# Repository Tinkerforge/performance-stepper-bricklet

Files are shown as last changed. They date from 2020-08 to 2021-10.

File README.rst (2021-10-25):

Performance Stepper Bricklet
============================

**This Bricklet is currently in development.**

This repository contains the firmware source code and the hardware design
files. The documentation generator configs can be found at
https://github.com/Tinkerforge/generators

Repository Content
------------------

software/:
 * examples/: Examples for all supported languages
 * build/: Compiled files
 * src/: Source code of firmware
 * Makefile: Makefile to build project

hardware/:
 * Contains KiCad project files and additionally schematics as PDF

datasheets/:
 * Contains datasheets for sensors and complex ICs that are used

Hardware
--------

The hardware is designed with the open source EDA Suite KiCad
(http://www.kicad.org). Before you are able to open the files,
you have to install the Tinkerforge kicad-libraries
(https://github.com/Tinkerforge/kicad-libraries). You can either clone
them directly in hardware/ or clone them in a separate folder and
symlink them into hardware/
(ln -s kicad_path/kicad-libraries project_path/hardware). After that you
can open the .pro file in hardware/ with KiCad and from there view and
modify the schematics and the PCB layout.

Software
--------

If you want to do your own Brick/Bricklet firmware development we highly
recommend that you use our build environment setup script and read the
tutorial (https://www.tinkerforge.com/en/doc/Tutorials/Tutorial_Build_Environment/Tutorial.html).

To compile the C code we recommend you to install the newest GNU Arm Embedded
Toolchain (https://launchpad.net/gcc-arm-embedded/+download).
You also need to install bricklib2 (https://github.com/Tinkerforge/bricklib2).

You can either clone it directly in software/src/ or clone it in a
separate folder and symlink it into software/src/
(ln -s bricklib_path/bricklib2 project_path/software/src/). Finally make sure to
have CMake installed (http://www.cmake.org/cmake/resources/software.html).

After that you can build the firmware by invoking make in software/.
The firmware (.zbin) can then be found in software/build/ and uploaded
with brickv (click button "Flashing" on start screen).

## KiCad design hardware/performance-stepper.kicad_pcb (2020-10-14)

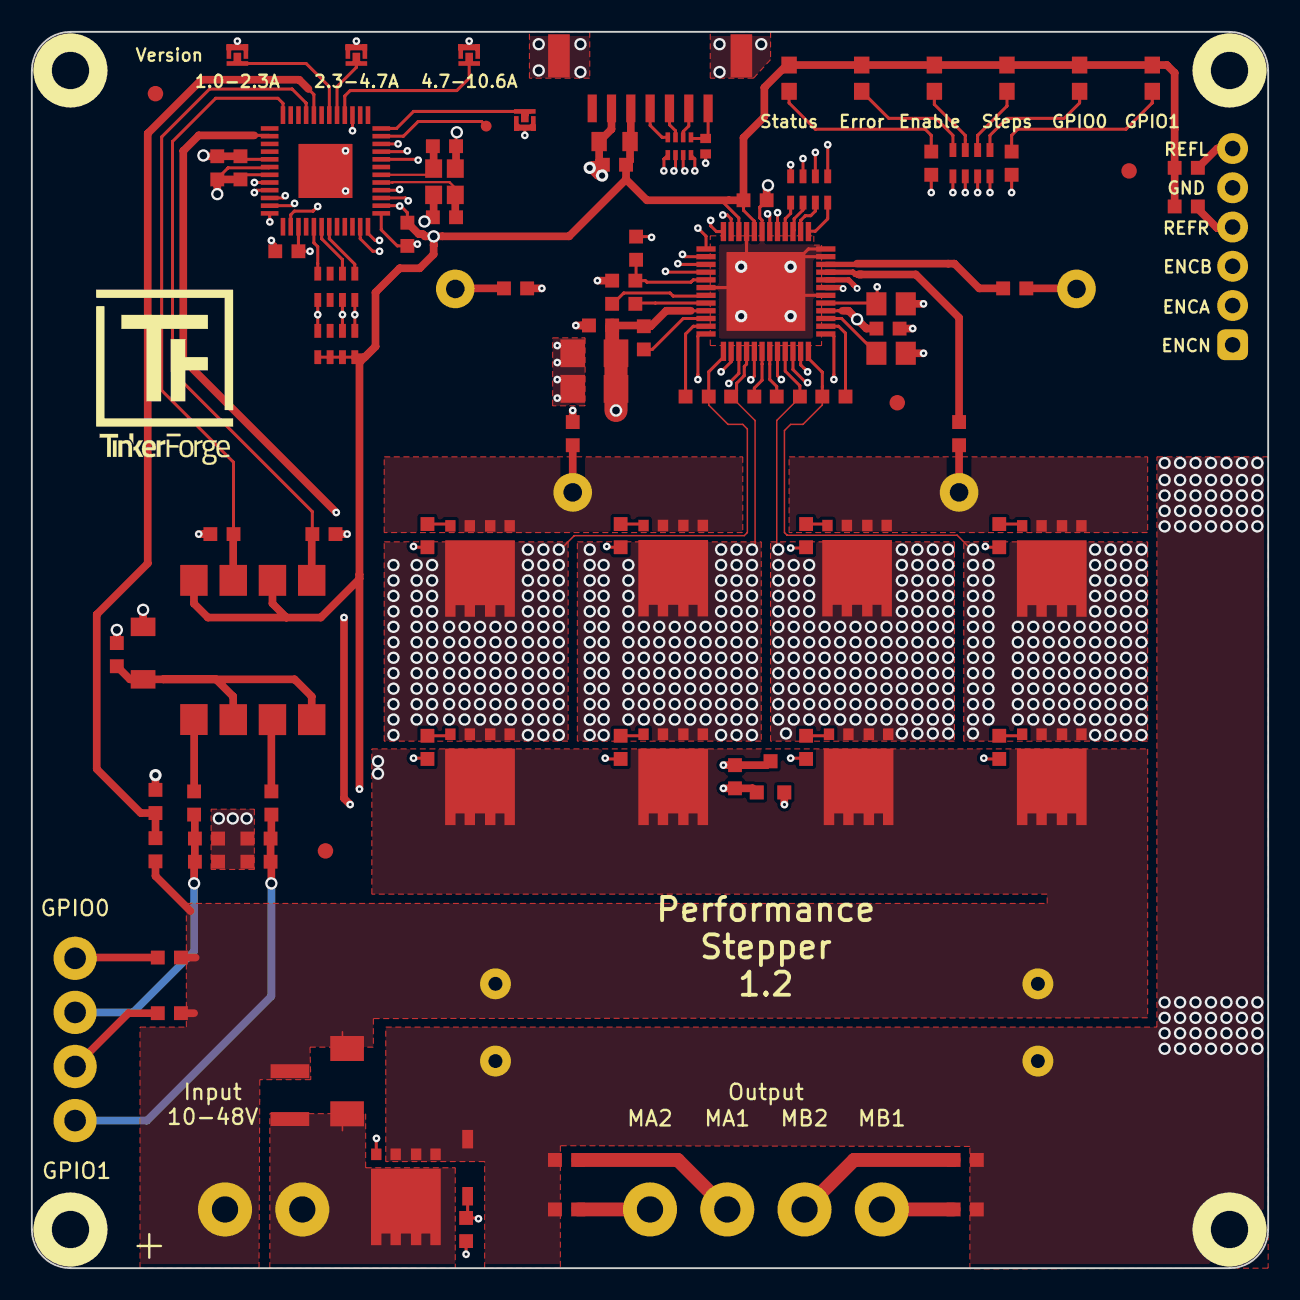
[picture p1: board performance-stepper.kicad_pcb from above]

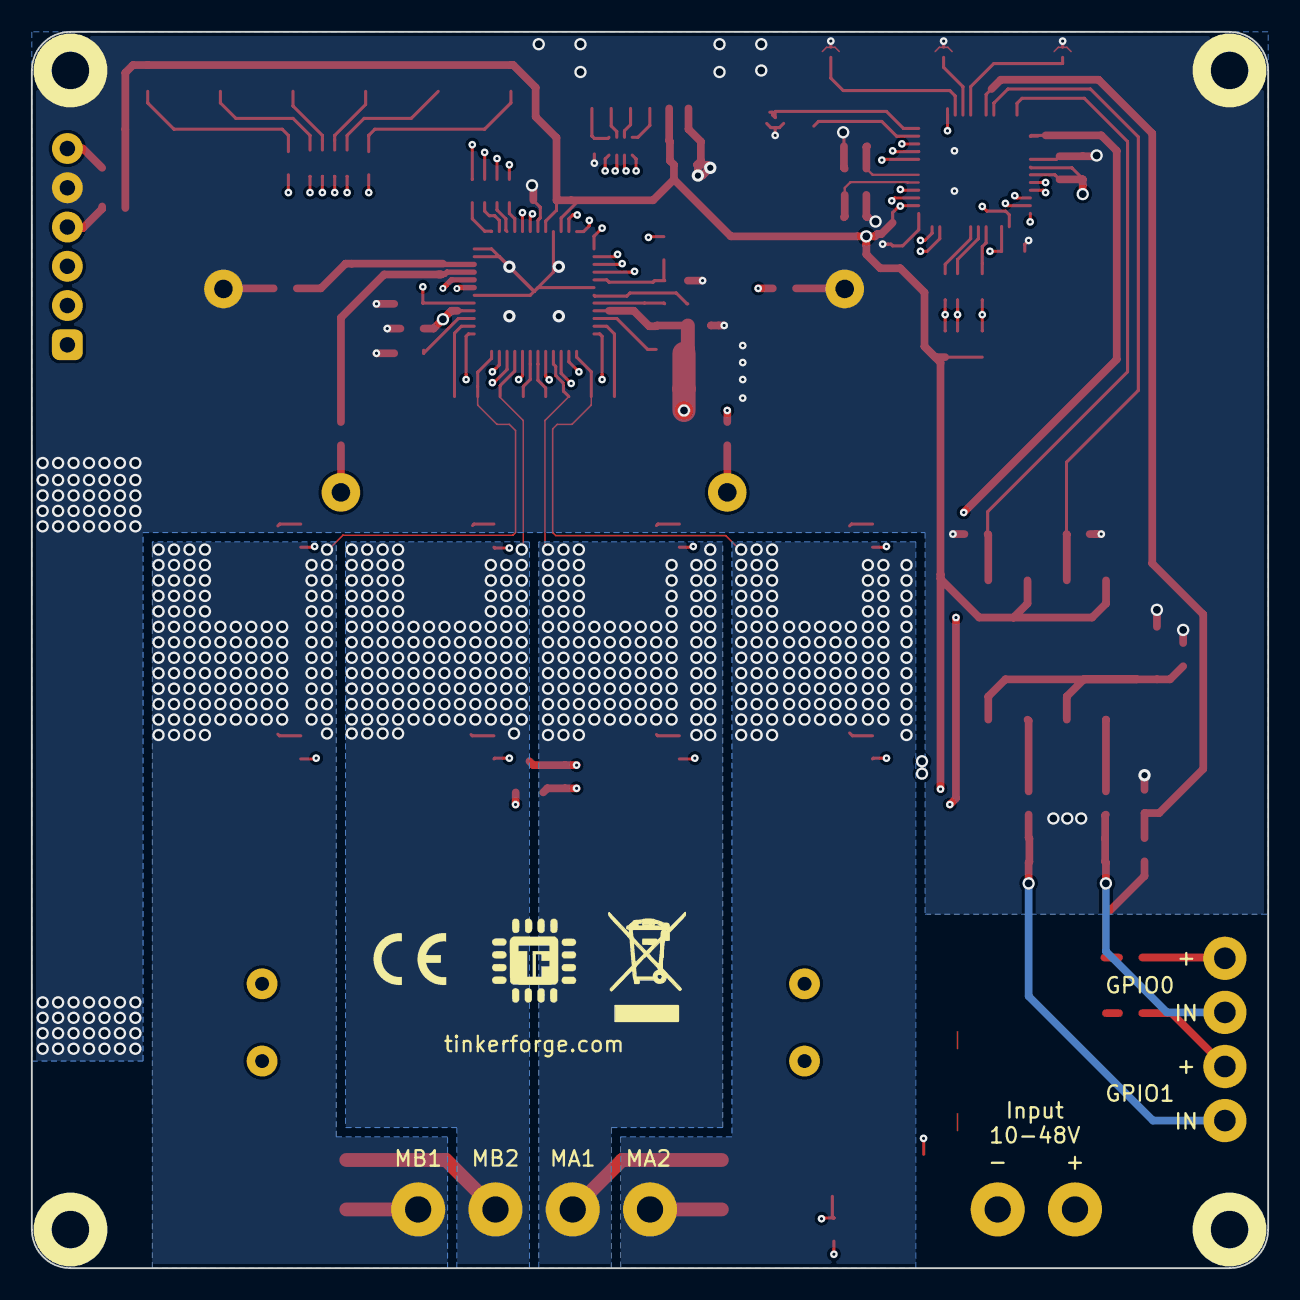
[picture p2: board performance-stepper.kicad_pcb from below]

Board: 4 copper layers, 80.0 x 80.0 mm, 112 parts (2 on the bottom side), 98 nets.

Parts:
C1, C4: 10pF; C0603F
C2, C9, C19, C30, C104: 100nF; C0603F
C3: 220nF; C0603F
C5, C11, C12, C23, C24, C25: 100nF/100V; C0603F
C6, C7: 2,2uF/16V; C0805E
C8, C13, C14, C15, C16: 470nF/25V; C0603F
C10: 22nF/100V; C0603F
C17, C18: 2,2uF/100V; C1206E
C20, C21: 220uF/100V/UVY2A221MHD1TO; ELKO_RAD_12
C26, C27, C28, C29: 1nF/100V; C0603F
C101: 10uF; C0805
C102: 220pF; C0402F
C103: 1uF; C0603F
D1: Z12V; SOD-123
D2: Z3,3V; MiniMelf
D3: red; D0603E
D4, D5, D6, D7, D101: blue; D0603E
D8: SMBJ48CA; SMB
Fiducial_Mark: VAL**; Fiducial_Mark
Fiducial_Mark#2, Fiducial_Mark#3, Fiducial_Mark#4: VAL**; Fiducial_Mark
P1: VIN; OQ_2P_5mm_Vertical_Black
P2: OUT; OQ_4P_5mm_Vertical
P3: GPIO; OQ_4P_Vertical
P4: PROTO; pin_array_1x6-P2mm_D1mm
P5: L; SolderJumper
P6: M; SolderJumper
P7: S; SolderJumper
P101: CON-SENSOR2; CON-SENSOR2_180
P102: DEBUG; DEBUG_PAD
P103: BOOT; SolderJumper
Q1, Q2, Q3, Q4, Q5, Q6, Q7, Q8, Q9: CSD19533Q5A; SON_5x6mm
R1: 2,2; R0603F
R2, R3, R4, R5, R12, R13, R14, R15: 10; R0603F
R6, R7, R8, R9: 47; R0603F
R10, R11: DNP; MSR-3
R16: 100k; R0603F
R17, R18, R19, R20, R25, R26: 1k; R0603F
R21, R22: 4,7k; R0603F
R23, R24: 2,2k; R0603F
R27: 10k; R0603F
R28: 150k; R0603F
R29: VG121048H101DP; 1210
R30, R31: DNP; R0603F
RP1: 10k; 0603X4
RP2: 22; 4X0603
RP3: 22; 0603X4
RP4: 1k; 0603X4
RP101: 82; 4X0402
U1: TMC5160A; eTQFP-48_7x7mm
U2: XMC1404; QFN48-EP2
U3: LTV-827; DIP_8_SMD
U4: TMP235; SOT23-3
U103, U104, U105, U106: DRILL; DRILL_NP
VAL: WEEE_7mm
VAL#2: CE_5mm
X1: 16MHz; CRYSTAL_2520

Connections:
CS_TMC: RP2.4, U2.40
DIAG0: RP3.2, U2.30
DIAG1: RP3.1, U2.31
DRV_ENN: RP3.4, U2.29
GND: C1.2, C2.2, C3.2, C4.2, C5.2, C6.1, C7.1, C8.1, C9.2, C12.2, C17.2, C18.2, C19.2, C20.2, C21.2, C23.2, C24.2, C25.2, C26.2, C27.1, C28.2, C29.1, C30.2, C101.1, C102.1, C103.1, C104.2, D1.1, D2.1, P4.5, P5.1, P6.1, P7.1, P101.2, P101.EP, P103.1, Q9.S, R7.1, R9.1, R10.1, R11.1, R17.1, R18.1, R21.1, R22.1, R27.1, U1.6, U1.11, U1.12, U1.19, U1.21, U1.30, U1.49, U2.17, U2.37, U2.EP, U4.3, X1.3
GPIO0: R17.2, U2.9, U3.7
GPIO1: R18.2, U2.12, U3.5
MISO_TMC: RP2.1, U2.35
MOSI_TMC: RP2.2, U2.36
unnamed: C1.1, U2.41, X1.1
unnamed: C4.1, U2.42, X1.2
unnamed: C6.2, U1.3
unnamed: C7.2, R1.2, U1.5
unnamed: C8.2, R1.1, U1.29
unnamed: C10.1, U1.31
unnamed: C10.2, U1.32
unnamed: C11.2, U1.34
unnamed: C13.1, C28.1, P2.3, Q5.S, Q6.D, U1.45
unnamed: C13.2, U1.43
unnamed: C14.1, C26.1, P2.4, Q1.S, Q2.D, U1.48
unnamed: C14.2, U1.2
unnamed: C15.1, C27.2, P2.1, Q7.S, Q8.D, U1.37
unnamed: C15.2, U1.35
unnamed: C16.1, C29.2, P2.2, Q3.S, Q4.D, U1.40
unnamed: C16.2, U1.42
unnamed: C23.1, D2.2, U3.2, U3.4
unnamed: C24.1, P3.2, R19.1, R21.2
unnamed: C25.1, P3.4, R20.1, R22.2
unnamed: C102.2, P101.7, RP101.5
unnamed: D1.2, Q9.G, R16.1
unnamed: D3.2, RP4.4
unnamed: D4.2, RP4.1
unnamed: D5.2, R25.1
unnamed: D6.2, RP4.2
unnamed: D7.2, RP4.3
unnamed: D8.2, P1.2, Q9.D, R29.2
unnamed: D101.2, R26.1
unnamed: P3.1, R23.1
unnamed: P3.3, R24.1
unnamed: P4.1, U1.25
unnamed: P4.2, U1.24
unnamed: P4.3, U1.23
unnamed: P4.4, R31.1, U1.18
unnamed: P4.6, R30.1, U1.17
unnamed: P5.2, U2.4
unnamed: P6.2, U2.5
unnamed: P7.2, U2.6
unnamed: P101.4, RP101.8
unnamed: P101.5, RP101.7
unnamed: P101.6, RP101.6
unnamed: P102.1, U2.47
unnamed: P103.2, U2.48
unnamed: Q1.G, R2.1
unnamed: Q2.G, R3.1
unnamed: Q2.S, Q6.S, R6.1, R10.2
unnamed: Q3.G, R4.1
unnamed: Q4.G, R5.1
unnamed: Q4.S, Q8.S, R8.1, R11.2
unnamed: Q5.G, R12.1
unnamed: Q6.G, R13.1
unnamed: Q7.G, R14.1
unnamed: Q8.G, R15.1
unnamed: R2.2, U1.1
unnamed: R3.2, U1.47
unnamed: R4.2, U1.41
unnamed: R5.2, U1.39
unnamed: R6.2, U1.9
unnamed: R7.2, U1.10
unnamed: R8.2, U1.8
unnamed: R9.2, U1.7
unnamed: R12.2, U1.44
unnamed: R13.2, U1.46
unnamed: R14.2, U1.36
unnamed: R15.2, U1.38
unnamed: R19.2, U3.1
unnamed: R20.2, U3.3
unnamed: R25.2, U2.20
unnamed: R26.2, U2.26
unnamed: RP1.5, RP3.8, U1.27
unnamed: RP1.6, RP3.7, U1.26
unnamed: RP1.8, RP3.5, U1.28
unnamed: RP2.5, U1.13
unnamed: RP2.6, U1.14
unnamed: RP2.7, U1.15
unnamed: RP2.8, U1.16
unnamed: RP4.5, U2.24
unnamed: RP4.6, U2.23
unnamed: RP4.7, U2.22
unnamed: RP4.8, U2.21
S-CLK: RP101.2, U2.45
S-CS: RP101.1, U2.44
S-MISO: RP101.4, U2.3
S-MOSI: RP101.3, U2.46
SCK_TMC: RP2.3, U2.39
TEMP: U2.14, U4.2
VCC: C2.1, C3.1, C9.1, C19.1, C30.1, C101.2, C103.2, C104.1, D3.1, D4.1, D5.1, D6.1, D7.1, D101.1, P101.3, R30.2, R31.2, RP1.1, RP1.2, RP1.3, RP1.4, U1.20, U1.22, U2.18, U2.19, U2.27, U2.38, U3.6, U3.8, U4.1
V_GPIO: C5.1, C11.1, C12.1, C17.1, C18.1, C20.1, C21.1, D8.1, P1.1, Q1.D, Q3.D, Q5.D, Q7.D, R16.2, R23.2, R24.2, R28.2, R29.1, U1.4, U1.33
V_Sense: R27.2, R28.1, U2.8

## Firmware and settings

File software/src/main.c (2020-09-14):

/* performance-stepper-bricklet
 * Copyright (C) 2019 Olaf Lüke <olaf@tinkerforge.com>
 *
 * main.c: Initialization for Performance Stepper Bricklet
 *
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
 * You should have received a copy of the GNU Lesser General Public
 * License along with this library; if not, write to the
 * Free Software Foundation, Inc., 59 Temple Place - Suite 330,
 * Boston, MA 02111-1307, USA.
 */

#include <stdio.h>
#include <stdbool.h>

#include "configs/config.h"

#include "bricklib2/bootloader/bootloader.h"
#include "bricklib2/hal/system_timer/system_timer.h"
#include "bricklib2/logging/logging.h"
#include "bricklib2/os/coop_task.h"
#include "communication.h"
#include "tmc5160.h"
#include "gpio.h"
#include "voltage.h"

// We run communication and bootloader tick in task,
// so we can yield to tmc5160 task from within the getter.
CoopTask main_task;
void main_tick_task(void) {
	while(true) {
		bootloader_tick();
		communication_tick();
		coop_task_yield();
	}
}

int main(void) {
	logging_init();
	logd("Start Performance Stepper Bricklet\n\r");

	communication_init();
	coop_task_init(&main_task, main_tick_task);
	tmc5160_init();
	gpio_init();
	voltage_init();

	while(true) {
		coop_task_tick(&main_task);
		tmc5160_tick();
		gpio_tick();
		voltage_tick();
	}
}

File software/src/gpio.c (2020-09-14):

/* performance-stepper-bricklet
 * Copyright (C) 2020 Olaf Lüke <olaf@tinkerforge.com>
 *
 * gpio.c: Driver for GPIO inputs/interrupts
 *
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
 * You should have received a copy of the GNU Lesser General Public
 * License along with this library; if not, write to the
 * Free Software Foundation, Inc., 59 Temple Place - Suite 330,
 * Boston, MA 02111-1307, USA.
 */

#include "gpio.h"
#include "configs/config_gpio.h"

#include "communication.h"
#include "bricklib2/hal/system_timer/system_timer.h"

#include "xmc_gpio.h"
#include "xmc_eru.h"
#include "xmc_scu.h"

#define gpio_0_handler IRQ_Hdlr_5
#define gpio_1_handler IRQ_Hdlr_6

typedef struct {
	XMC_GPIO_PORT_t *const port;
	const uint8_t pin;
	uint8_t irq_n;
} GPIOPins;

static const GPIOPins gpio_pins[GPIO_CHANNEL_NUM] = {
	{GPIO_0_PIN, GPIO_0_IRQ_N},
	{GPIO_1_PIN, GPIO_1_IRQ_N}
};

static const GPIOPins gpio_led_pins[GPIO_CHANNEL_NUM] = {
	{GPIO_0_LED_PIN, 0},
	{GPIO_1_LED_PIN, 0}
};

GPIO gpio;

static inline void __attribute__((optimize("-O3"))) __attribute__ ((section (".ram_code"))) handle_new_gpio_value(const uint8_t channel) {
	// Check if value changed
	const bool value = XMC_GPIO_GetInput(gpio_pins[channel].port, gpio_pins[channel].pin);
	if(gpio.last_interrupt_value[channel] == value) {
		return;
	}

	// Save value
	gpio.last_interrupt_value[channel] = value;

	// Turn interrupt off if debounce is enabled
	if(gpio.debounce != 0) {
		gpio.last_interrupt_time[channel]  = system_timer_get_ms();
		NVIC_DisableIRQ(gpio_pins[channel].irq_n);
		NVIC_ClearPendingIRQ(gpio_pins[channel].irq_n);
	}

	// TODO: handle callback here

	// Check if action is necessary
	if(value && (gpio.action[channel] & PERFORMANCE_STEPPER_GPIO_ACTION_EMERGENCY_STOP_RISING_EDGE)) {
		gpio.stop_emergency = true;
	} else if(value && (gpio.action[channel] & PERFORMANCE_STEPPER_GPIO_ACTION_NORMAL_STOP_RISING_EDGE)) {
		gpio.stop_normal    = true;
	} else if(!value && (gpio.action[channel] & PERFORMANCE_STEPPER_GPIO_ACTION_EMERGENCY_STOP_FALLING_EDGE)) {
		gpio.stop_emergency = true;
	} else if(!value && (gpio.action[channel] & PERFORMANCE_STEPPER_GPIO_ACTION_NORMAL_STOP_FALLING_EDGE)) {
		gpio.stop_normal    = true;
	}

	// Set LED
	if(gpio.gpio_led_flicker_state[channel].config == PERFORMANCE_STEPPER_GPIO_LED_CONFIG_SHOW_GPIO_ACTIVE_HIGH) {
		if(value) {
			XMC_GPIO_SetOutputLow(gpio_led_pins[channel].port, gpio_led_pins[channel].pin);
		} else {
			XMC_GPIO_SetOutputHigh(gpio_led_pins[channel].port, gpio_led_pins[channel].pin);
		}
	} else if(gpio.gpio_led_flicker_state[channel].config == PERFORMANCE_STEPPER_GPIO_LED_CONFIG_SHOW_GPIO_ACTIVE_LOW) {
		if(value) {
			XMC_GPIO_SetOutputHigh(gpio_led_pins[channel].port, gpio_led_pins[channel].pin);
		} else {
			XMC_GPIO_SetOutputLow(gpio_led_pins[channel].port, gpio_led_pins[channel].pin);
		}
	}
}

void __attribute__((optimize("-O3"))) __attribute__ ((section (".ram_code"))) gpio_0_handler(void) {
	handle_new_gpio_value(0);
}

void __attribute__((optimize("-O3"))) __attribute__ ((section (".ram_code"))) gpio_1_handler(void) {
	handle_new_gpio_value(1);
}
/*
bool gpio_is_motion_disabled(void) {
	return (gpio.action[0] & )
}*/

void gpio_init(void) {
    memset(&gpio, 0, sizeof(GPIO));

	gpio.action[0]                        = PERFORMANCE_STEPPER_GPIO_ACTION_NONE;
	gpio.action[1]                        = PERFORMANCE_STEPPER_GPIO_ACTION_NONE;
	gpio.debounce                         = 200; // 200ms default
	gpio.stop_deceleration                = 0xFFFF;
	gpio.gpio_led_flicker_state[0].config = PERFORMANCE_STEPPER_GPIO_LED_CONFIG_SHOW_GPIO_ACTIVE_LOW;
	gpio.gpio_led_flicker_state[1].config = PERFORMANCE_STEPPER_GPIO_LED_CONFIG_SHOW_GPIO_ACTIVE_LOW;


	// Init GPIO IRQs
	const XMC_GPIO_CONFIG_t gpio_pin_config = {
		.mode             = XMC_GPIO_MODE_INPUT_TRISTATE,
		.input_hysteresis = XMC_GPIO_INPUT_HYSTERESIS_LARGE
	};

	const XMC_ERU_ETL_CONFIG_t sync_etl_0_config = {
		.input_a                = GPIO_0_INPUT_A,
		.input_b                = GPIO_0_INPUT_B,
		.enable_output_trigger  = 1,
		.edge_detection         = XMC_ERU_ETL_EDGE_DETECTION_BOTH,
		.output_trigger_channel = GPIO_0_TRG_CHANNEL,
		.source                 = GPIO_0_SOURCE
	};

	XMC_GPIO_Init(GPIO_0_PIN, &gpio_pin_config);
	XMC_ERU_ETL_Init(GPIO_0_ERU, GPIO_0_ETL_CHANNEL, &sync_etl_0_config);
	XMC_ERU_OGU_SetServiceRequestMode(GPIO_0_ERU, GPIO_0_OGU_CHANNEL, XMC_ERU_OGU_SERVICE_REQUEST_ON_TRIGGER);
	NVIC_SetPriority(GPIO_0_IRQ_N, GPIO_0_IRQ_PRIO);
    XMC_SCU_SetInterruptControl(GPIO_0_IRQ_N, GPIO_0_IRQ_CTRL);
	NVIC_ClearPendingIRQ(GPIO_0_IRQ_N);
	NVIC_EnableIRQ(GPIO_0_IRQ_N);


    const XMC_ERU_ETL_CONFIG_t sync_etl_1_config = {
		.input_a                = GPIO_1_INPUT_A,
		.input_b                = GPIO_1_INPUT_B,
		.enable_output_trigger  = 1,
		.edge_detection         = XMC_ERU_ETL_EDGE_DETECTION_BOTH,
		.output_trigger_channel = GPIO_1_TRG_CHANNEL,
		.source                 = GPIO_1_SOURCE
	};
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

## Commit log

2019-11-22 Add auto-generated Silent Stepper Bricklet 2.0 firmware stub
    [cmake_config_custom.txt]
2019-12-02 Add coop spi fifo support
2020-01-22 added schematic
    [silent-stepper-v2.sch, tmc.sch]
2020-01-24 schematic and pcb changes
    [silent-stepper-v2.sch, tmc.sch]
2020-01-29 pcb design
    [silent-stepper-v2.kicad_pcb, silent-stepper-v2.sch, tmc.sch]
2020-01-31 finished prototype ready for revision
    [silent-stepper-v2.kicad_pcb, silent-stepper-v2.sch, tmc.sch]
2020-02-03 changes protection circuit
    [silent-stepper-v2.kicad_pcb, tmc.sch]
2020-02-05 ready for prototype
    [silent-stepper-v2.kicad_pcb]
2020-02-06 DRC control and ordered prototyp
    [silent-stepper-v2.kicad_pcb, tmc.sch]
2020-03-27 Add ifdef support for development board and prototype
2020-04-01 changed GPIO interrupt pin and added zener value
    [silent-stepper-v2.kicad_pcb, tmc.sch]
2020-04-02 added Voltage In Sense
    [silent-stepper-v2.kicad_pcb, silent-stepper-v2.sch]
2020-04-03 Add initial GPIO and voltage support
2020-04-07 Add support for LED blinkenlights
2020-04-08 changed shunt resistors
    [silent-stepper-v2.kicad_pcb, tmc.sch]
2020-04-08 changed varistor value and footprint
    [silent-stepper-v2.kicad_pcb, tmc.sch]
2020-04-15 Convert 24 bit signed integer correctly
    [communication.c]
2020-04-15 TMC is enabled if enabled pin is low
2020-04-15 Scale delay time correctly
    [communication.c]
2020-05-08 changed resistor
    [silent-stepper-v2.kicad_pcb]
2020-07-09 added Temperature Sensor, added pullups and ground to proto header, removed screwholes, moved 47 ohm inline resitors for better shunt clearance, removed no-silkscreen area on bottomlayer, removed big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
    [silent-stepper-v2.kicad_pcb, silent-stepper-v2.sch, tmc.sch]
2020-07-14 changed resistor array footprint
    [silent-stepper-v2.kicad_pcb, tmc.sch]
2020-07-23 new hardware version
    [silent-stepper-v2.kicad_pcb, silent-stepper-v2.sch]
2020-08-06 changed C6, C7 footprint to 0805 and updated SON_5x6 footprint
    [silent-stepper-v2.kicad_pcb, silent-stepper-v2.sch, tmc.sch]
2020-09-09 version 2.2 : changed name, added shunt version solderjumpers, moved pins for boot and debug pad, changed silkscreen
    [performance-stepper-v2.kicad_pcb, performance-stepper-v2.sch]
2020-09-09 changed silkscreen
    [performance-stepper-v2.kicad_pcb]
2020-09-09 Add temperature measurements and update defaults
2020-09-09 changed version number, changed silkscreen
    [performance-stepper.kicad_pcb, performance-stepper.sch, tmc.sch]
2020-09-14 Rename to "Performance Stepper Bricklet"
2020-10-14 updated all OQ connectors with new F.Fab layer
    [performance-stepper.kicad_pcb]
2021-10-25 Update KiCad link
    https://www.kicad.org/blog/2021/10/Avoid-links-to-former-kicad-domain/

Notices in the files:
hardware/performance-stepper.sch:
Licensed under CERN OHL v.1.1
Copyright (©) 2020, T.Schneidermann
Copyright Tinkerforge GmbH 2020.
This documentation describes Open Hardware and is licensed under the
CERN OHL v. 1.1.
